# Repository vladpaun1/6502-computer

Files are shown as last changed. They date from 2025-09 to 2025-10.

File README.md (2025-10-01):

# 6502-computer
A personal project building a 65c02 based 8-bit breadboard computer and coding a lightweight custom OS for it

## Shopping list
### Mouser Order  
Items:
- W65C02S6TPG-14 — 8-bit Microprocessor — €11,11
- W65C22S6TPG-14 — I/O Controller Interface IC — €11,30  
- AS6C62256-55PCN — SRAM 32Kx8 55ns — €4,44  
- AT28C256-15PU — EEPROM 32Kx8 150ns — €9,99  
- ECS-100AX-010 — Oscillator 1MHz DIP-14 — €2,30  
- ECS-100AX-143 — Oscillator 14.31818MHz DIP-14 — €2,12  
- SN74HC138N — 3-to-8 Decoder — €1,08  
- SN74HC14N — Hex Schmitt-Trigger Inverter — €0,91  
- SN74HC245N — Octal Bus Transceiver — €0,71  
- SN74HC00N (x3) — Quad 2-Input NAND Gate — €1,83  
- SN74HC595N (x2) — 8-bit Shift Register — €2,88  
- SN74HC157N — Quad Data Selector/Multiplexer — €2,10  
- MCP130-485HI/TO — Supervisory Circuit — €0,46  
- BB830T (x2) — 830-Tie Point Transparent Breadboard — €18,10  
- LCD 16x2 RGB — Display Module — €11,01  
- K104K20X7RH5UH5 (x10) — 0.1µF MLCC Leaded Capacitors — €1,78  
- 68024-116HLF — 1x16 Pin Header — €0,83  

### Amazon Order  
Items:  
- 840-Piece Breadboard Jumper Wire Set (14 lengths, with clips)  
- TL866II Plus Universal Programmer (with 10 adapters)  
- AC to DC 9V 2A Power Supply (EU plug, center positive)  
- ELEGOO Electronic Fun Kit (breadboard, resistors, capacitors, LEDs, pots, etc.)  

## Dependencies

To build and flash ROMs for this project you’ll need:

- **Python 3.12+**  
  Used for helper scripts in the `tools/` directory.

- **[minipro-git](https://aur.archlinux.org/packages/minipro-git)**  
  Utility for programming EEPROMs/Flash devices with the TL866xx programmer.  
  On Arch-based systems you can install it from the AUR:  
  ```bash
  yay -S minipro-git
  ```
- **[ACME Cross Assembler](https://sourceforge.net/projects/acme-crossass/)**  
  A 6502/65C02 assembler used to build flat binary ROM images.  
  On Arch Linux it’s available in the official repos:
  ```bash
  sudo pacman -S acme
  ```
  Example usage:
  ```bash
  acme -f plain -o software/build/rom.bin software/src/main.asm
  ```
- **Hardware CAD (KiCad)**
  We use **KiCad 8** for schematics and PCB layout.  
  Install on Arch
  ```bash
  sudo pacman -S kicad kicad-symbols kicad-footprints kicad-packages3d kicad-templates
  ```

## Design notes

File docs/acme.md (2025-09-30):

# ACME Assembler Notes

This project uses the **[ACME Cross Assembler](https://github.com/meonwax/acme-crossass)** to assemble 6502/65C02 programs into flat binary ROM images.  
On Arch Linux it’s packaged as `acme`:

```
sudo pacman -S acme
```

## Upstream Documentation

The full ACME docs are installed with the package (on Arch they live under `/usr/share/doc/acme/`).  
Useful files include:

- `QuickRef.txt` – cheatsheet of directives and syntax  
- `Help.txt` – main manual  
- `Example.txt` – sample assembly programs  
- `AddrModes.txt` – addressing modes reference  

If you don’t have these locally, you can also view them online here:

- [QuickRef.txt](https://github.com/martinpiper/ACME/blob/master/docs/QuickRef.txt)  
- [Help.txt](https://github.com/martinpiper/ACME/blob/master/docs/Help.txt)  

## Cheatsheet (common usage)

- **Comments**: `;` starts a comment  
- **Labels**:  
  ```
  start:      lda #$42
              sta $0000
  ```
- **Constants**: `$xx` hex, `%xxxx` binary, `123` decimal  
- **Directives**:  
  - `!to "file.bin", plain` → output as flat binary  
  - `* = $8000` → set program counter (origin)  
  - `!byte $01, $02, $03` → define raw bytes  
  - `!word $1234, $ABCD` → define 16-bit words (little endian)  
- **Vectors** (for 65C02 reset/IRQ/NMI):  
  ```
  * = $FFFA
  !word nmi, reset, irq
  ```
- **Including other files**:  
  ```
  !src "other.asm"
  ```

## Example Program

```
!to "software/build/rom.bin", plain   ; output binary
* = $8000                             ; load address

reset:
    lda #$42
    sta $0000
    rts

nmi:  rti
irq:  rti

* = $FFFA                             ; interrupt vectors
!word nmi, reset, irq
```

Assemble with:

```
acme -f plain -o software/build/rom.bin software/src/main.asm
```

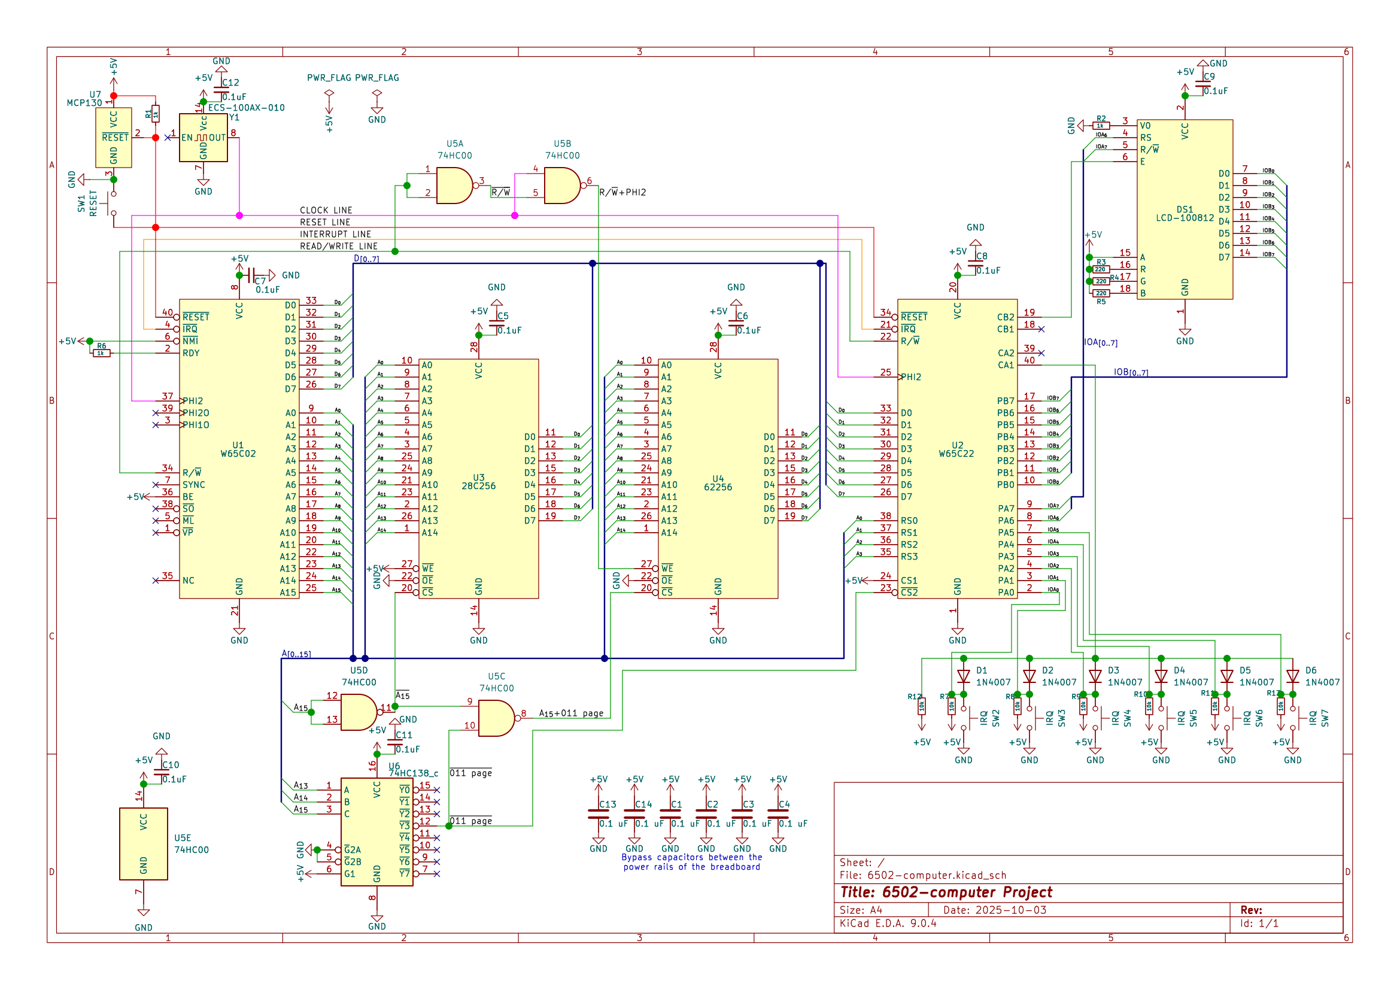
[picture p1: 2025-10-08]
docs/plots/img/6502-computer-1.png

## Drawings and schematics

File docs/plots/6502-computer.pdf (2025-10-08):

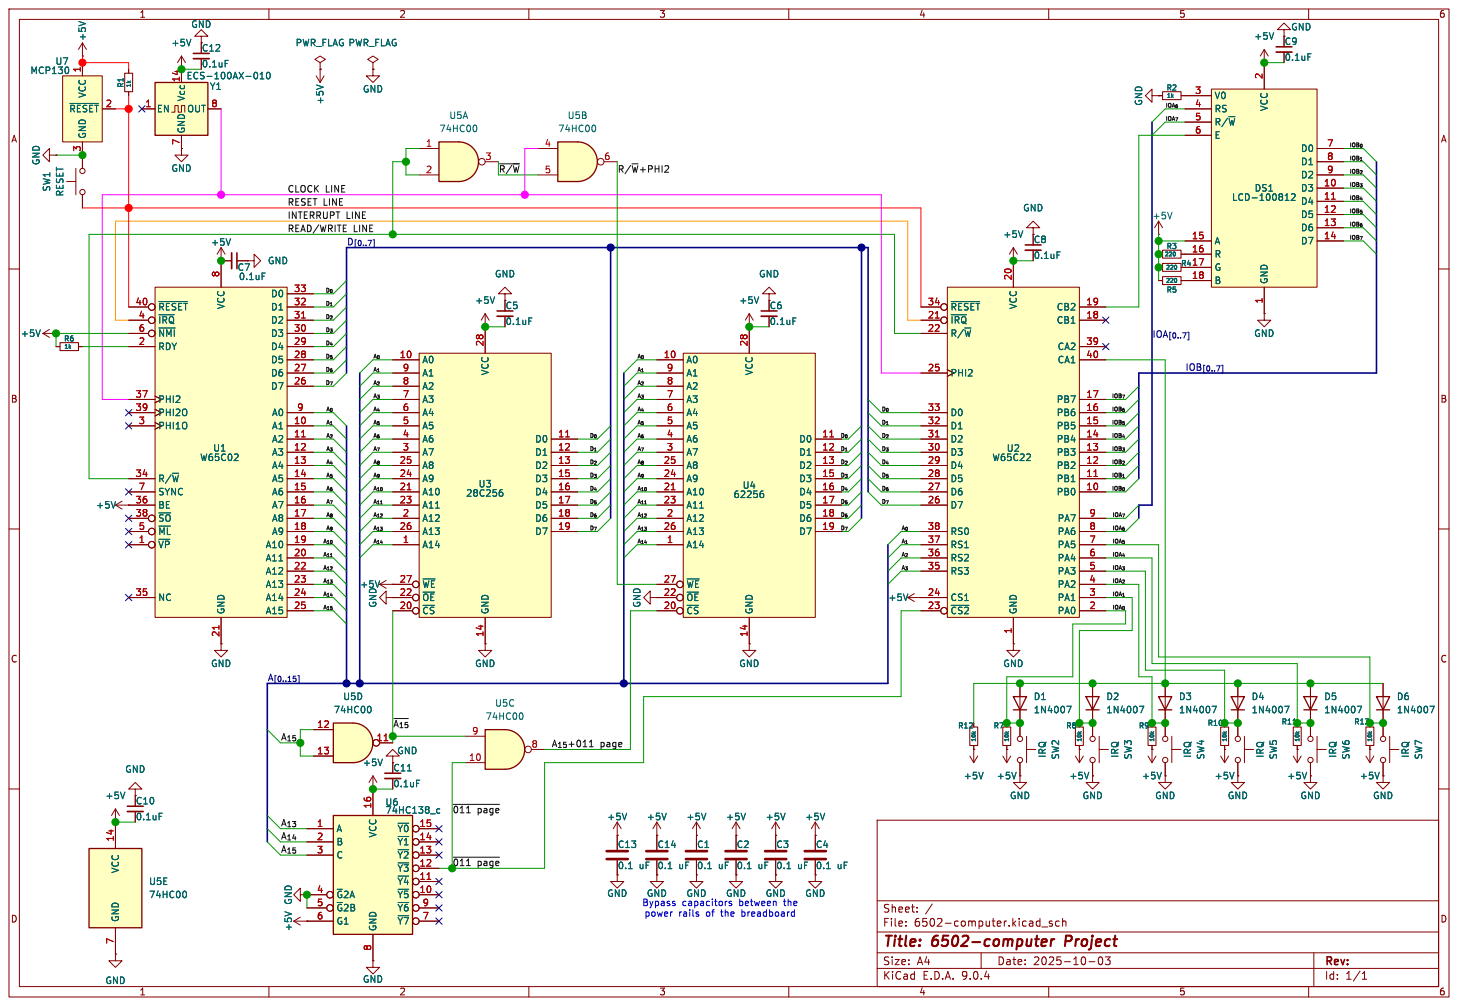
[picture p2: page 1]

7 OUT 8Y1 ECS-100AX-010 GND GND GND GND

D_{7} CLOCK LINE
INTERRUPT LINE RESET LINE

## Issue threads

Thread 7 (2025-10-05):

Complete KiCad schematic of the wiring so far

vladpaun1, 2025-10-05:
Create and finalize a KiCad schematic that documents the current wiring of CPU, EEPROM, VIA, SRAM, and LCD connections.

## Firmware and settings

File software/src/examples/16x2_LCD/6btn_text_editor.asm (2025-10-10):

!to "software/build/6btn_text_editor.bin", plain
!cpu 65c02

; =============================================================================
; 6btn_text_editor — W65C02 + VIA + HD44780 (16x2 visible / 40x2 DDRAM)
; Features: cursor mode / insert mode, 6-button CA1 IRQ dispatch,
;           horizontal windowing (WIN_OFF), backspace-shift, and line-2 status.
; Notes:
; - Zero Page is reserved for hot pointers and one scratch byte.
; - lcd_get_addr returns AC in A (clobbers X).
; - lcd_read_data returns data in A (clobbers Y).
; =============================================================================
* = $8000

; =============================================================================
; Hardware map (VIA + LCD bus)
; =============================================================================
!addr PORTB   = $6000
!addr PORTA   = $6001
!addr DDRB    = $6002
!addr DDRA    = $6003
!addr PCR     = $600c
!addr IFR     = $600d
!addr IER     = $600e

; ---- Port A mapping: PA7=RW, PA6=RS, PA5..PA0 = buttons (active-low) ----
RW = %10000000                  ; PA7
RS = %01000000                  ; PA6

; ---- VIA PCR/CB2: only bits 7..5 affect CB2; read-modify-write preserves others ----
CB2_HIGH_BITS = %11100000       ; CB2 = High output
CB2_LOW_BITS  = %11000000       ; CB2 = Low output
PRESERVE_MASK = %00011111       ; keep non-CB2 control bits 4..0

; =============================================================================
; Buttons (active-low on PA5..PA0)
; =============================================================================
BTN_MODE  = %00000001  ; PA0
BTN_LEFT  = %00000010  ; PA1
BTN_UP    = %00000100  ; PA2
BTN_DOWN  = %00001000  ; PA3
BTN_RIGHT = %00010000  ; PA4
BTN_ENTER = %00100000  ; PA5
BTN_MASK  = %00111111

; =============================================================================
; HD44780 geometry/opcodes (40x2 DDRAM, 16x2 visible window)
; =============================================================================
LCD_COLS        = 16
LCD_LINE_LEN    = 40
LCD_LAST_COL    = 39
LCD_MAX_WINOFF  = LCD_LINE_LEN - LCD_COLS         ; 24

AC_LINE0_BASE   = %00000000                        ; $00
AC_LINE1_BASE   = %01000000                        ; $40
AC_LINE0_LAST   = %00100111                        ; $27

CMD_SET_DDRAM   = %10000000

; Cursor / shift instructions
SHIFT_DISP_LEFT  = %00011000
SHIFT_DISP_RIGHT = %00011100
CURSOR_LEFT      = %00010000
CURSOR_RIGHT     = %00010100

; =============================================================================
; Zero Page (keep hot pointers + one temp only)
; =============================================================================
text_ptr          = $00         ; [ZP+0..1] 16-bit pointer for print_msg
jmp_ptr           = $02         ; [ZP+2..3] 16-bit indirect jump target
tmp               = $04         ; [ZP+4]    general temp (button latch etc.)
; $05.. reserved for future

; =============================================================================
; RAM state (main memory)
; =============================================================================
MODE_ADDRESS            = $0200  ; 0..NUM_MODES-1
INSERT_TYPE_ADDRESS     = $0201  ; 0..NUM_INSERT_TYPES-1
LAST_CURSOR_POS         = $0202  ; last DDRAM addr read (7-bit)
CURRENT_INSERT          = $0203  ; current glyph to insert/edit
CURRENT_SPECIAL_INDEX   = $0204  ; index into special_table
WIN_OFF                 = $0205  ; window offset 0..LCD_MAX_WINOFF (24)
RESET_INSERT_TYPE       = $0206  ; flag: 1 when entering INSERT mode
BS_TARGET_ADDR          = $0207  ; final DDRAM command after backspace

; =============================================================================
; Modes / Insert types and UI strings (ROM data)
; =============================================================================
NUM_MODES   = 2
MODE_CURSOR = 0
MODE_INSERT = 1

mode_texts:
    !word mode1_text, mode2_text
mode1_text: !text "<cursor mode>",0
mode2_text: !text "i:",0

NUM_INSERT_TYPES     = 4
INSERT_TYPE_CHAR     = 0
INSERT_TYPE_UPPER    = 1
INSERT_TYPE_NUM      = 2
INSERT_TYPE_SPECIAL  = 3

insert_type_default_texts:
    !word insert_type1_default, insert_type2_default, insert_type3_default, insert_type4_default
insert_type1_default: !text "<char_lo>:",0
insert_type2_default: !text "<char_up>:",0
insert_type3_default: !text "<num>:",0
insert_type4_default: !text "<special>:",0

; Special glyph set (wraps)
SPECIAL_COUNT = 25
special_table:
    !byte ' ','.',',','-','_','?','!',';',':','+','/','\\','*','(',')','[',']','{','}','<','>','=','@','#','&'

; Power-up banner
msg: !text "Hello, world!",0

; =============================================================================
; Reset / Init
; =============================================================================
reset:
    sei
    ldx #$FF
    txs

    jsr initialize_lcd
    jsr init_irq_for_ca1
    cli                         ; enable IRQs

    ; Greeting on power-up
    lda #<msg      : sta text_ptr
    lda #>msg      : sta text_ptr + 1
    jsr print_msg

    ; Capture current cursor and reset window
    jsr lcd_get_addr
    sta LAST_CURSOR_POS
    stz WIN_OFF

    ; Initial editor state
    lda #MODE_CURSOR        : sta MODE_ADDRESS
    lda #INSERT_TYPE_CHAR   : sta INSERT_TYPE_ADDRESS
    lda #'a'                : sta CURRENT_INSERT

    jsr show_current_mode_on_line2

main_loop:
    jmp main_loop

; =============================================================================
; IRQ (CA1 falling edge). Buttons on PA5..PA0 are active-low.
; BIT #mask + BEQ branches when bit is 0 (i.e., pressed).
; =============================================================================
irq:
    pha
    phx
    phy

    lda IFR
    and #%00000010
    beq irq_done                 ; not a CA1 IRQ

    ; Latch & clear CA1 early, keep only button bits
    lda PORTA
    and #BTN_MASK
    sta tmp                      ; save buttons (still active-low)

    ; Also sample DDRAM address once for helpers
    jsr lcd_get_addr
    sta LAST_CURSOR_POS

    ; Dispatch on buttons
    lda tmp
    bit #BTN_MODE   : beq irq_mode
    bit #BTN_LEFT   : beq irq_left
    bit #BTN_UP     : beq irq_up
    bit #BTN_DOWN   : beq irq_down
    bit #BTN_RIGHT  : beq irq_right
    bit #BTN_ENTER  : beq irq_enter
    ; else nothing pressed/handled

    jmp irq_done

irq_mode:   jsr toggle_modes        : jmp irq_done
irq_left:   jmp dispatch_left
irq_up:     jmp dispatch_up
irq_down:   jmp dispatch_down
irq_right:  jmp dispatch_right
irq_enter:  jmp dispatch_enter

irq_done:
    ply
    plx
    pla
    rti

; =============================================================================
; Cursor helpers
; =============================================================================
; reset_cursor: restore cursor to LAST_CURSOR_POS.
reset_cursor:
    lda LAST_CURSOR_POS
    ora #CMD_SET_DDRAM
    jsr lcd_instruction
    rts
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

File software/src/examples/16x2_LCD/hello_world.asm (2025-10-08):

!to "software/build/hello_world.bin", plain
!cpu 65c02

* = $8000

!addr PORTB   = $6000
!addr PORTA   = $6001
!addr DDRB    = $6002
!addr DDRA    = $6003
!addr PCR     = $600c

RW = %10000000                  ; PA7
RS = %01000000                  ; PA6

; PCR/CB2 control (only bits 7..5 affect CB2). RMW to preserve other bits.
CB2_HIGH_BITS = %11100000       ; CB2 = High output
CB2_LOW_BITS  = %11000000       ; CB2 = Low output
PRESERVE_MASK = %00011111       ; keep bits 4..0



msg:    !text "Hello, world!",0

reset:
    ldx #$FF
    txs

    jsr initialize_lcd

    ldx #0
print_loop:
    lda msg, x
    beq loop
    jsr print_char
    inx
    jmp print_loop

loop:
    jmp loop

; RS=1, RW=0
print_char:
    jsr lcd_wait
    pha
    sta PORTB
    lda #RS
    sta PORTA
    jsr lcd_strobe
    pla
    rts

initialize_lcd:
    lda #%11111111
    sta DDRB
    lda #%11100000
    sta DDRA

    lda #%00111000
    jsr lcd_instruction
    lda #%00001110
    jsr lcd_instruction
    lda #%00000110
    jsr lcd_instruction
    lda #%00000001
    jsr lcd_instruction 

    rts

lcd_instruction:
    jsr lcd_wait
    sta PORTB
    lda #$00
    sta PORTA
    jsr lcd_strobe
    rts

; Pulse E on CB2: HIGH then LOW (RMW preserve)
lcd_strobe:
    pha
    lda PCR
    and #PRESERVE_MASK
    ora #CB2_HIGH_BITS
    sta PCR
    lda PCR
    and #PRESERVE_MASK
    ora #CB2_LOW_BITS
    sta PCR
    pla
    rts


; Busy-flag poll (read DB7 while E is HIGH)
lcd_wait:
    pha
    lda #%00000000
    sta DDRB                      ; PB inputs
@busy:
    lda #RW                       ; RS=0, RW=1
    sta PORTA
    ; E HIGH
    lda PCR
    and #PRESERVE_MASK
    ora #CB2_HIGH_BITS
    sta PCR
    lda PORTB
    pha
    ; E LOW
    lda PCR
    and #PRESERVE_MASK
    ora #CB2_LOW_BITS
    sta PCR
    pla
    and #%10000000                ; DB7 busy?
    bne @busy
    lda #%11111111
    sta DDRB                      ; PB outputs
    pla
    rts
nmi: rti
irq: rti

* = $FFFA
!word nmi, reset, irq

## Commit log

2025-09-30 added assembler and simple asm programs
2025-09-30 added kicad dependency
2025-10-01 added anothe led example
2025-10-02 Add KiCad project + custom W65C02 symbol; ignore caches/backups
    [6502-computer.kicad_pcb, 6502-computer.kicad_sch]
2025-10-02 added 65c22 symbol and added it to schematics
    [6502-computer.kicad_sch]
2025-10-02 added EEPROM and SRAM schematics
2025-10-03 added wirings, still have to finish control logic
2025-10-03 finished schematic wiring
2025-10-03 first plot of current state
2025-10-06 connected interrupt line
2025-10-06 hooked up VIA PORTA to 6 buttons
2025-10-07 added insert mode and insert types
2025-10-07 finished insert mode
2025-10-08 updated schematic
2025-10-08 update code to work on new schematic
2025-10-08 added space character to insert mode
2025-10-09 added uppercase insert type
2025-10-09 buggy 40 char lines
    [6btn_text_editor.asm]
2025-10-09 fix line 2 shift
    [6btn_text_editor.asm]
2025-10-09 backspace works on whole line, need to fix shifting
    [6btn_text_editor.asm]
2025-10-10 fixed jump to home and jump to end handlers
    [6btn_text_editor.asm]
2025-10-10 fix irq start and up/down in cursor mode
    [6btn_text_editor.asm]
